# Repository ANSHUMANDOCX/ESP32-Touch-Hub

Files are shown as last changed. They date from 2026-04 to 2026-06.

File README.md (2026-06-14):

# ESP32-S3 Smart Hub

## Description
This is a ESP32-S3 Based HUB paired with a touch screen that can be used for anything that one wants but for me i will be using it to connect all my ESP32 project and control it from one place and get a whole lot more connected experience between my project.

---
## Parts Used
- ESP32 S3 Used as the brains of the system
- CH340C for onboard programming. 
- 3.5" ILI9488 SPI touch display (MSP3520 module) for UI interaction
- Battery-powered with USB-C charging and intelligent load sharing
- Onboard SD card for storing web assets, UI resources, and sensor logs
- 3 tactile buttons + passive buzzer for physical interaction and alerts
- Charging status indicators both physical and UI based
---
## Technicals 
- The board will have dual volages 5V and 3.3v for the TFT and ESP32.
- It uses a load sharing circuit where when the battery is charging the board will be powered from the USB
- I will pair a 1800mah Lipo Battery so i can get a considerable amount of battery life.
- the board is using a MT3608 and ME6217C33M5G ics for 5v and 3.3v regulator along with a MCP73833 for charging the battery

## Firmware
THe code is tested just put your wifi and password and its ready to go 

## PCB SCHEMATIC and CAD 






## BUILD 
Demo Link https://youtube.com/shorts/PqJHbwtBgcA







## BOM
| Product Name | Quantity | Price ($) | Vendor |
|---|---:|---:|---|
| [ME6217C33M5G 3.3V LDO Regulator](https://sharvielectronics.com/product/me6217c33m5g-3-3v-800ma-fixed-ldo-voltage-regulator-sot-23-5-package/) | 1 | 0.30 | Sharvi Electronics |
| [ESP32-S3-WROOM-1 N16R8](https://sharvielectronics.com/product/esp32-s3-wroom-1-n16r8-16mb-flash-memory-wifi-and-bluetooth-module-41-smd-package/) | 1 | 4.51 | Sharvi Electronics |
| [FS8205A Dual N-Channel MOSFET](https://sharvielectronics.com/product/fs8205a-dual-n-channel-power-mosfet-lithium-battery-protection-tssop-8-package/) | 1 | 0.80 | Sharvi Electronics |
| [DW01A Battery Protection IC](https://sharvielectronics.com/product/dw01a-lithium-battery-protection-ic-sot23-6/) | 1 | 0.55 | Sharvi Electronics |
| [MT3608 Step-Up Converter IC](https://sharvielectronics.com/product/mt3608-high-efficiency-1-2mhz-2a-step-up-converter-sot23-6-package/) | 1 | 0.85 | Sharvi Electronics |
| [Micro SD Card Socket 9-Pin SMD](https://sharvielectronics.com/product/micro-sd-memory-card-socket-9pin-smd/) | 1 |0.60| Sharvi Electronics |
| [MCP73833 Li-Ion Charger IC](https://robu.in/product/mcp73833-ami-un-microchip-battery-charger-for-1-cell-of-li-ion-li-pol-battery-6v-input-4-2v-1a-charge-msop-10) | 1 | 1.93 | Robu.in |
| [AO3401 P-Channel MOSFET](https://robu.in/product/ao3401a-umwyoutai-semiconductor-co-ltd-30v-4-2a-50m%cf%8910v-1-4w-400mv-1-piece-p-channel-sot-23-mosfets-rohs) | 1 | 0.37 | Robu.in |
| [3.5" TFT Touchscreen Display](https://techiesms.com/product/3-5-inch-tft-touchscreen-display/) | 1 | 11.62 | Techiesms |
| Passives (Resistors, Capacitors, Pull-ups, etc.) | Assorted | 8 | Sharvi Electronics |
|PCB||2|ALLPCB|
|SHIPPING||1||
|Total||35||

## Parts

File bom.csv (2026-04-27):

Designator | Footprint | Quantity | Value | LCSC Part #
BZ1 | Buzzer_12x9.5RM7.6 | 1 | Buzzer
C1 | 0603 | 1 | 1uF
C10, C17, C19, C9 | 0603 | 4 | 4.7uF
C11, C12, C5 | 0603 | 3 | 22uf
C13, C14, C15, C16, C18, C20 | 0603 | 6 | 100nF
C2, C3, C4 | 0603 | 3 | 0.1uF
C23, C6 | 0603 | 2 | 10uF
C7, C8 | 0603 | 2 | 0.1
D1 | D_SOD-123 | 1 | 1N4148W
D13, D3, D4, D5, D6, D8 | 0603 | 6 | LED
D2, D7 | D_SMA | 2 | SS34
J1 | JST_XH_B2B-XH-AM_1x02_P2.50mm_Vertical | 1 | Conn_01x02_Pin
J2 | USB_C_Receptacle_GCT_USB4105-xx-A_16P_TopMnt_Horizontal | 1 | USB_C_Receptacle_USB2.0_16P
L1 | IND-SMD_L4.0-W4.0 | 1 | 22uH
LCD1 | MSP3520 | 1 | MSP3520
Q1 | SOT-23 | 1 | AO3401A
Q2, Q3 | SOT-23 | 2 | SS8050
Q4 | TSSOP-8_L4.4-W3.0-P0.65-LS6.4-BL-2 | 1 | ~
Q5 | SOT-23 | 1 | MMBT2222A
R1 | 0603 | 1 | 10K Therm
R10, R11, R21 | 0603 | 3 | 100R
R12, R4, R5, R6 | 0603 | 4 | 1K
R13, R14, R15, R18, R19, R27, R28 | 0603 | 7 | 10K
R16, R17 | 0603 | 2 | 5.1K
R2 | 0603 | 1 | 2.2k
R20 | 0603 | 1 | 470R
R22, R23, R7, R9 | 0603 | 4 | 100K
R3 | 0603 | 1 | 2K
R8 | 0603 | 1 | 750k
SW1, SW4, SW5 | SW_TH_Tactile_Omron_B3F-100x | 3 | SW_Push
SW2, SW3 | SW_Push_SPST_NO_Alps_SKRK | 2 | SW_Push
TF1 | TF-SMD_TF-CARD-H1.8 | 1 | ~
U1 | ESP32-S3-WROOM-1 | 1 | ESP32-S3-WROOM-1
U2 | SOIC-16_3.9x9.9mm_P1.27mm | 1 | CH340C
U3 | MSOP-10_3x3mm_P0.5mm | 1 | MCP73833-xxx-UN
U4 | SOT-23-5 | 1 | ME6217C33M5G
U5 | SOT-23-6 | 1 | DW01A
U6 | SOT-23-6 | 1 | MT3608

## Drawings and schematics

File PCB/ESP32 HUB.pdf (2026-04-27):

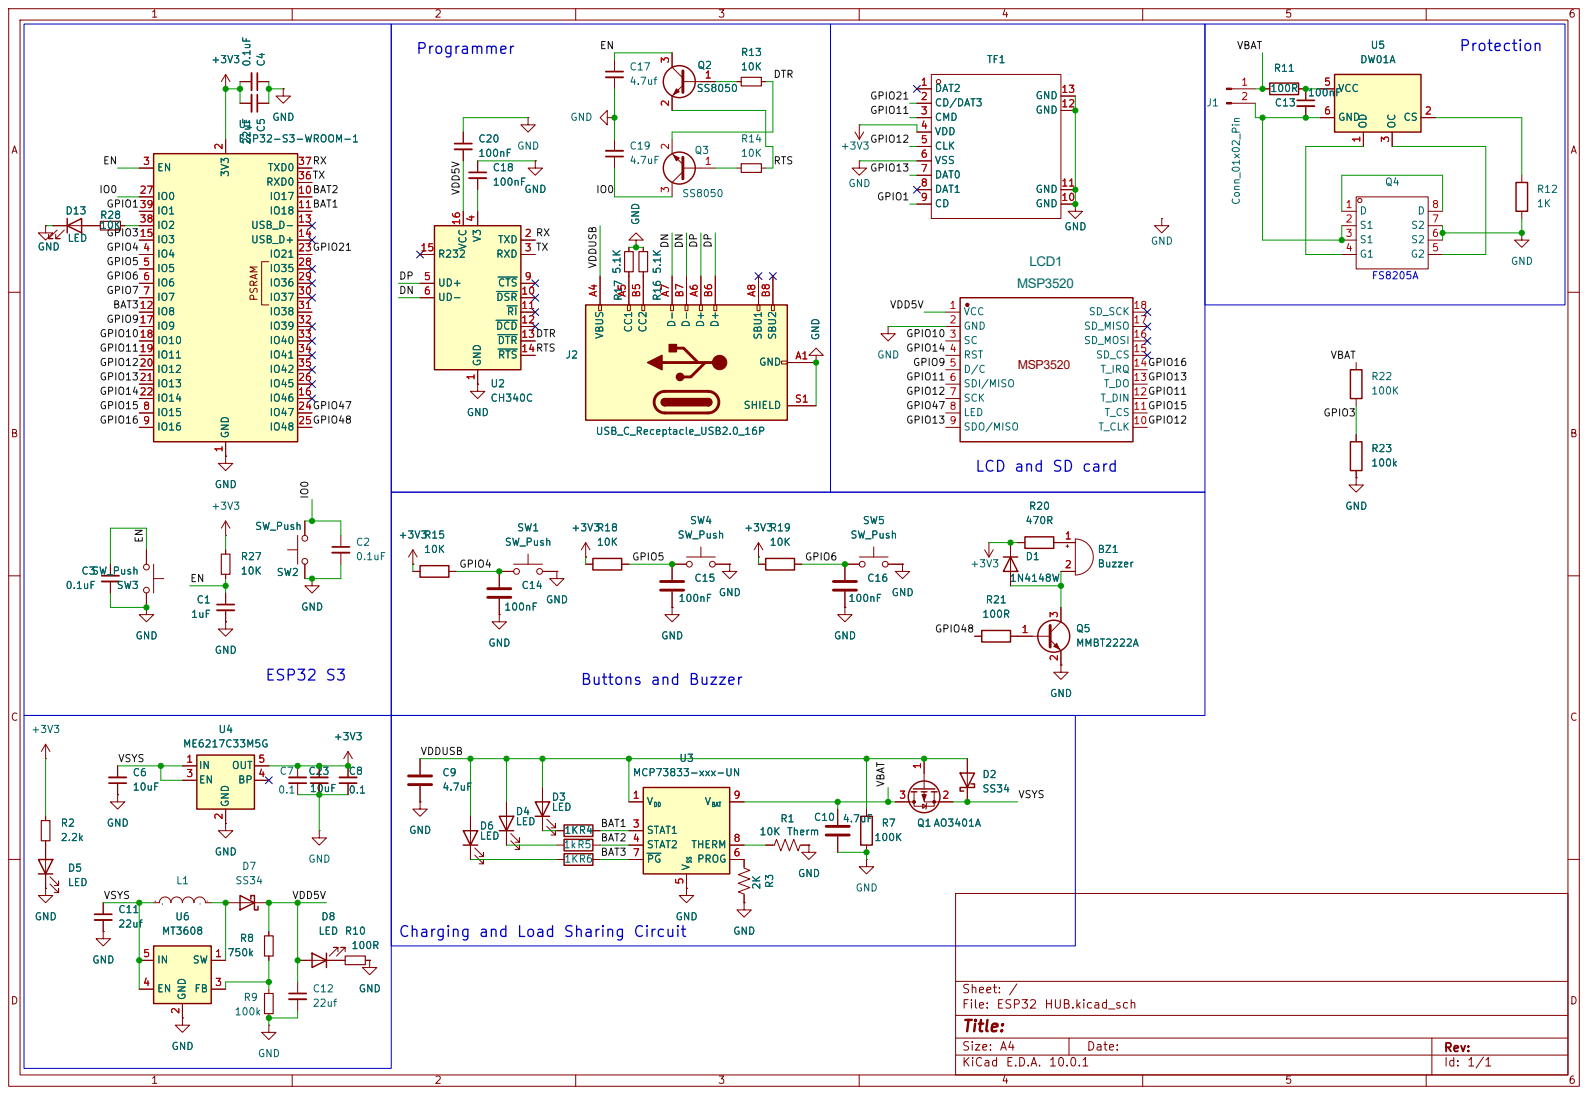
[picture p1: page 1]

4 UD+ 5 UD- 6 CTS 9 DSR 10 RI 11 DCD 12 DTR 13 RTS 14 R232 15 VCC 16 C18
GPIO1 Charging and Load Sharing Circuit

4 UD+ 5 UD- 6 CTS 9 DSR 10 RI 11 DCD 12 DTR 13 RTS 14 R232 15 VCC 16 U2CH340C PSRAM GND

LCD and SD card

Size: A4 | Rev:
KiCad E.D.A. 10.0.1 | Id: 1/1

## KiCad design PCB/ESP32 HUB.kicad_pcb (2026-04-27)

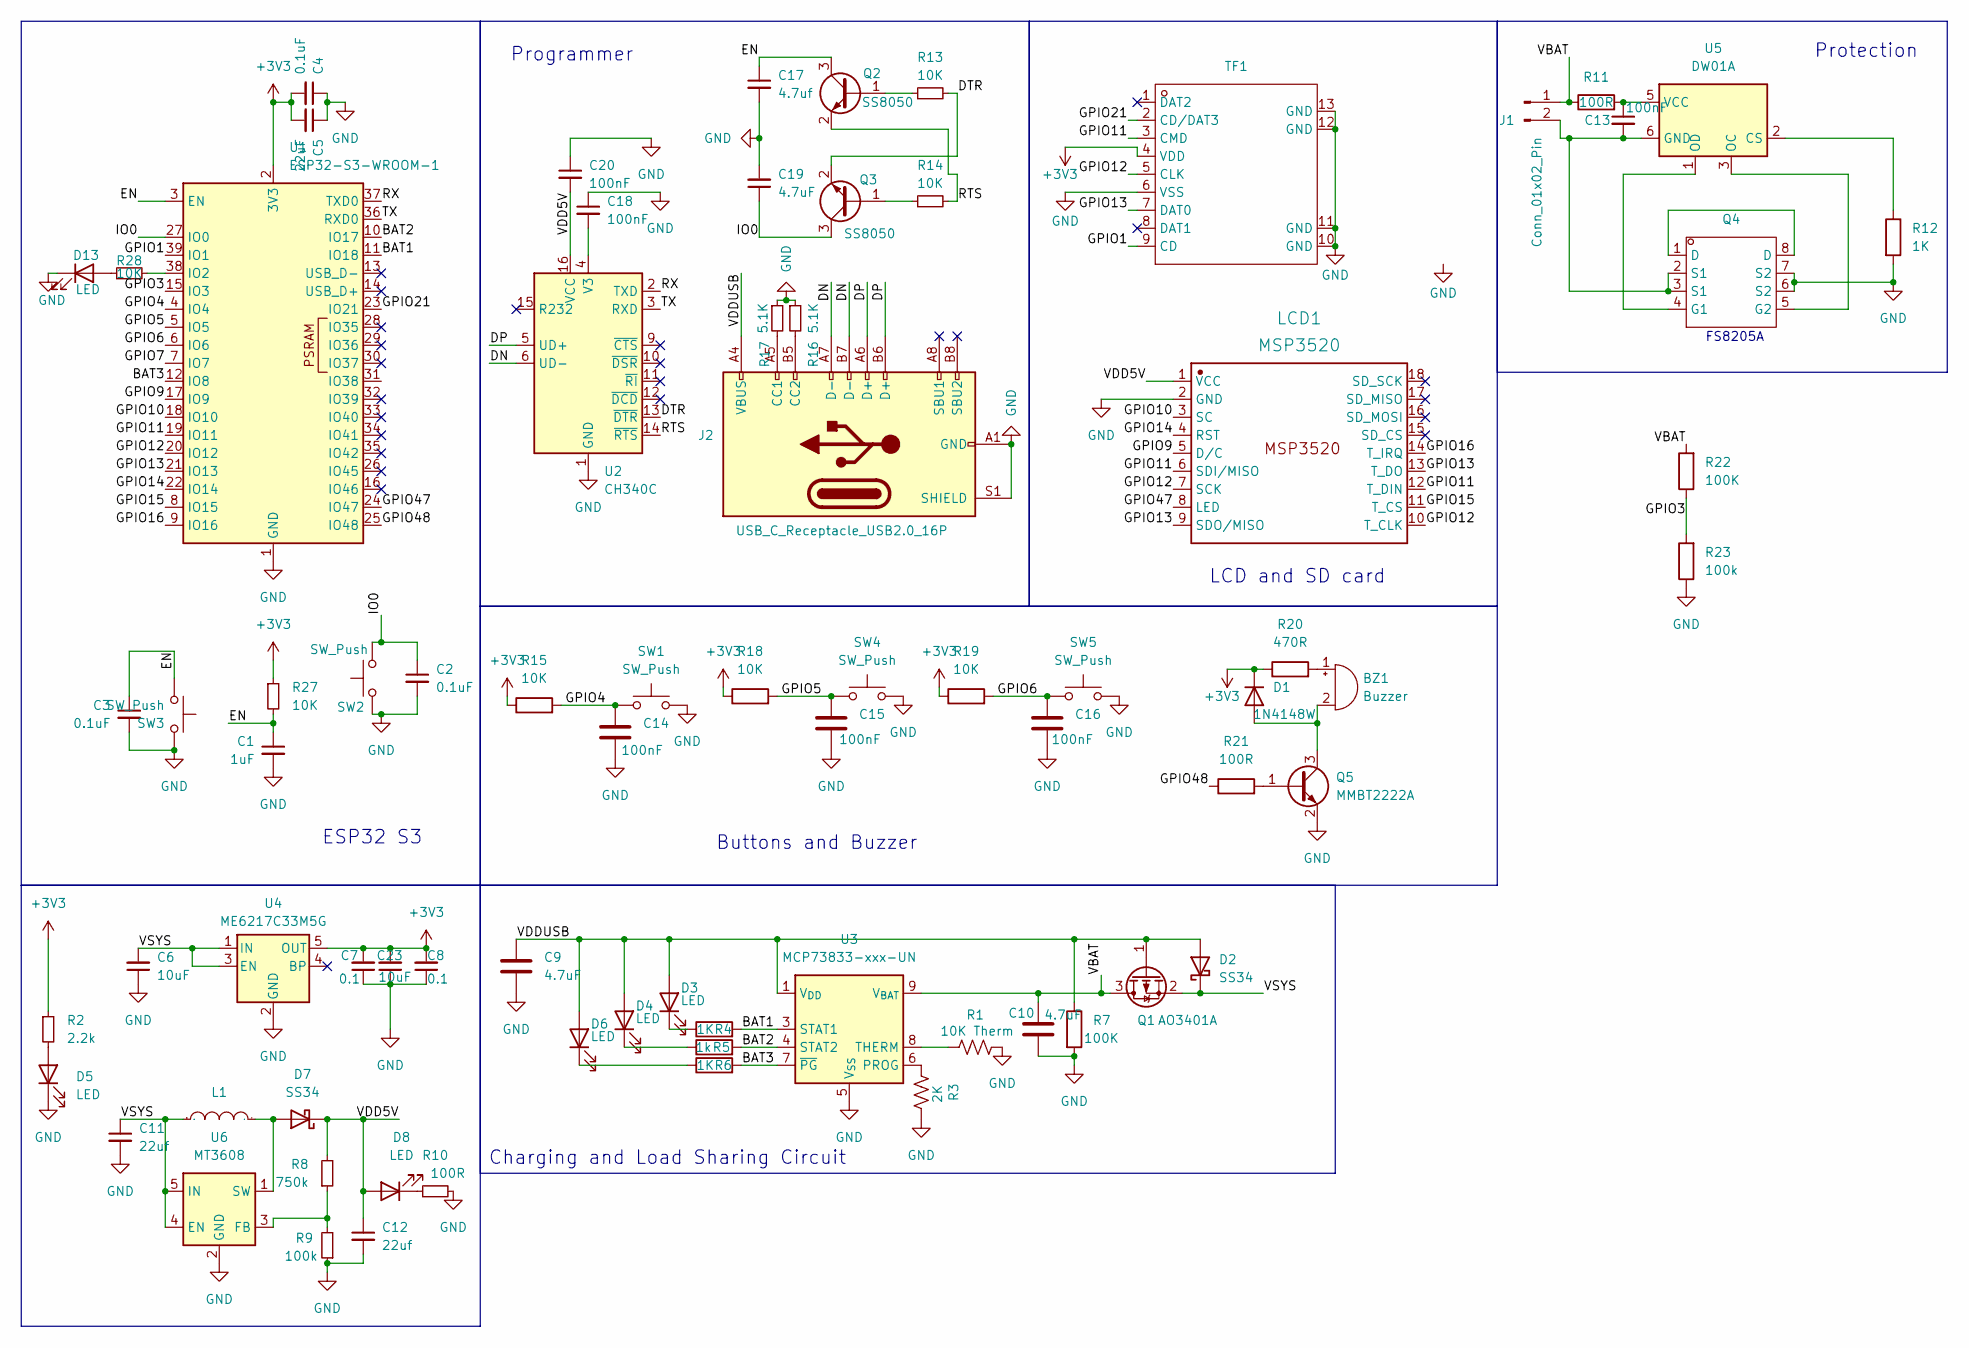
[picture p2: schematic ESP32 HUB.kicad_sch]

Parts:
BZ1: Buzzer; Buzzer_12x9.5RM7.6
C1: 1uF; C_0603_1608Metric
C2, C3, C4: 0.1uF; C_0603_1608Metric
C5: 22uF; C_0603_1608Metric
C6, C23: 10uF; C_0603_1608Metric_Pad1.08x0.95mm_HandSolder
C7, C8: 0.1; C_0603_1608Metric_Pad1.08x0.95mm_HandSolder
C9, C10: 4.7uF; C_0603_1608Metric
C11, C12: 22uf; C_0603_1608Metric
C13, C14, C15, C16: 100nF; C_0603_1608Metric
C17: 4.7uf; C_0603_1608Metric_Pad1.08x0.95mm_HandSolder
C18, C20: 100nF; C_0603_1608Metric_Pad1.08x0.95mm_HandSolder
C19: 4.7uF; C_0603_1608Metric_Pad1.08x0.95mm_HandSolder
D1: 1N4148W; D_SOD-123
D2, D7: SS34; D_SMA
D3, D4, D5, D6, D8, D13: LED; LED_0603_1608Metric
J1: Conn_01x02_Pin; JST_XH_B2B-XH-AM_1x02_P2.50mm_Vertical
J2: USB_C_Receptacle_USB2.0_16P; USB_C_Receptacle_GCT_USB4105-xx-A_16P_TopMnt_Horizontal
L1: 22uH; IND-SMD_L4.0-W4.0; Manufacturer Part ANR4030T220M; LCSC Part Name 22uH ±20% 1.4A 4x4x3mm
LCD1: MSP3520; Manufacturer Part MSP3520
Q1: AO3401A; SOT-23
Q2, Q3: SS8050; SOT-23
Q4: TSSOP-8_L4.4-W3.0-P0.65-LS6.4-BL-2; Manufacturer Part FS8205A; LCSC Part Name 2个N沟道 耐压:20V 电流:6A
Q5: MMBT2222A; SOT-23
R1: 10K Therm; R_0603_1608Metric_Pad0.98x0.95mm_HandSolder
R2: 2.2k; R_0603_1608Metric_Pad0.98x0.95mm_HandSolder
R3: 2K; R_0603_1608Metric_Pad0.98x0.95mm_HandSolder
R4, R6, R12: 1K; R_0603_1608Metric_Pad0.98x0.95mm_HandSolder
R5: 1k; R_0603_1608Metric_Pad0.98x0.95mm_HandSolder
R7, R22: 100K; R_0603_1608Metric_Pad0.98x0.95mm_HandSolder
R8: 750k; R_0603_1608Metric_Pad0.98x0.95mm_HandSolder
R9, R23: 100k; R_0603_1608Metric_Pad0.98x0.95mm_HandSolder
R10, R11, R21: 100R; R_0603_1608Metric_Pad0.98x0.95mm_HandSolder
R13, R14, R15, R18, R19, R27, R28: 10K; R_0603_1608Metric_Pad0.98x0.95mm_HandSolder
R16, R17: 5.1K; R_0603_1608Metric_Pad0.98x0.95mm_HandSolder
R20: 470R; R_0603_1608Metric_Pad0.98x0.95mm_HandSolder
SW1, SW4, SW5: SW_Push; SW_TH_Tactile_Omron_B3F-100x
SW2, SW3: SW_Push; SW_Push_SPST_NO_Alps_SKRK
TF1: TF-SMD_TF-CARD-H1.8; Manufacturer Part TF-CARD H1.8; LCSC Part Name 9P，自弹式TF卡座
U1: ESP32-S3-WROOM-1
U2: CH340C; SOIC-16_3.9x9.9mm_P1.27mm
U3: MCP73833-xxx-UN; MSOP-10_3x3mm_P0.5mm
U4: ME6217C33M5G; SOT-23-5
U5: DW01A; SOT-23-6
U6: MT3608; SOT-23-6

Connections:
+3V3: C4.2, C5.2, C7.2, C8.2, C23.2, D1.1 (K), R2.1, R15.1, R18.1, R19.1, R20.1, R27.1, TF1.4 (VDD), U1.2 (3V3), U4.5 (OUT)
/BAT1: R4.2, U1.11 (IO18), U3.3 (STAT1)
/BAT2: R5.2, U1.10 (IO17), U3.4 (STAT2)
/BAT3: R6.2, U1.12 (IO8), U3.7 (~PG)
/DN: J2.A7 (D-), J2.B7 (D-), U2.6 (UD-)
/DP: J2.A6 (D+), J2.B6 (D+), U2.5 (UD+)
/DTR: Q3.2 (E), R13.2, U2.13 (~DTR)
/EN: C1.1, C3.1, C17.1, Q2.3 (C), R27.2, SW3.1, U1.3 (EN)
/GPIO1: TF1.9 (CD), U1.39 (IO1)
/GPIO3: R22.1, R23.2, U1.15 (IO3)
/GPIO4: C14.1, R15.2, SW1.1, U1.4 (IO4)
/GPIO5: C15.1, R18.2, SW4.1, U1.5 (IO5)
/GPIO6: C16.1, R19.2, SW5.1, U1.6 (IO6)
/GPIO7: U1.7 (IO7)
/GPIO9: LCD1.5 (D/C), U1.17 (IO9)
/GPIO10: LCD1.3 (SC), U1.18 (IO10)
/GPIO11: LCD1.6 (SDI/MISO), LCD1.12 (T_DIN), TF1.3 (CMD), U1.19 (IO11)
/GPIO12: LCD1.7 (SCK), LCD1.10 (T_CLK), TF1.5 (CLK), U1.20 (IO12)
/GPIO13: LCD1.9 (SDO/MISO), LCD1.13 (T_DO), TF1.7 (DAT0), U1.21 (IO13)
/GPIO14: LCD1.4 (RST), U1.22 (IO14)
/GPIO15: LCD1.11 (T_CS), U1.8 (IO15)
/GPIO16: LCD1.14 (T_IRQ), U1.9 (IO16)
/GPIO21: TF1.2 (CD/DAT3), U1.23 (IO21)
/GPIO47: LCD1.8 (LED), U1.24 (IO47)
/GPIO48: R21.1, U1.25 (IO48)
/IO0: C2.1, C19.1, Q3.3 (C), SW2.1, U1.27 (IO0)
/RTS: Q2.2 (E), R14.2, U2.14 (~RTS)
/RX: U1.37 (TXD0), U2.2 (TXD)
/TX: U1.36 (RXD0), U2.3 (RXD)
/VBAT: C10.1, J1.1, Q1.3 (D), R11.1, R22.2, U3.9 (V_{BAT}), U3.10 (V_{BAT})
/VDD5V: C12.1, C20.2, D7.1 (K), D8.2 (A), LCD1.1 (VCC), R8.2, U2.16 (VCC)
/VDDUSB: C9.1, D2.2 (A), D3.2 (A), D4.2 (A), D6.2 (A), J2.A4 (VBUS), J2.A9 (VBUS), J2.B4 (VBUS), J2.B9 (VBUS), Q1.1 (G), R7.1, U3.1 (V_{DD}), U3.2 (V_{DD})
/VSYS: C6.2, C11.1, D2.1 (K), L1.1, Q1.2 (S), U4.1 (IN), U4.3 (EN), U6.4 (EN), U6.5 (IN)
GND: C1.2, C2.2, C3.2, C4.1, C5.1, C6.1, C7.1, C8.1, C9.2, C10.2, C11.2, C12.2, C14.2, C15.2, C16.2, C17.2, C18.1, C19.2, C20.1, C23.1, D5.1 (K), D13.1 (K), J2.A1 (GND), J2.A12 (GND), J2.B1 (GND), J2.B12 (GND), J2.S1 (SHIELD), LCD1.2 (GND), Q4.6 (S2), Q4.7 (S2), Q5.2 (E), R1.2, R3.2, R7.2, R9.1, R10.2, R12.2, R16.1, R17.1, R23.1, SW1.2, SW2.2, SW3.2, SW4.2, SW5.2, TF1.6 (VSS), TF1.10 (GND), TF1.11 (GND), TF1.12 (GND), TF1.13 (GND), U1.1 (GND), U1.40 (GND), U1.41 (GND), U2.1 (GND), U3.5 (V_{SS}), U4.2 (GND), U6.2 (GND)
unnamed: BZ1.1 (+), R20.2
unnamed: BZ1.2 (-), D1.2 (A), Q5.3 (C)
unnamed: D3.1 (K), R4.1
unnamed: D4.1 (K), R5.1
unnamed: D5.2 (A), R2.2
unnamed: D6.1 (K), R6.1
unnamed: D7.2 (A), L1.2, U6.1 (SW)
unnamed: D8.1 (K), R10.1
unnamed: D13.2 (A), R28.1
unnamed: C13.2, J1.2, Q4.2 (S1), Q4.3 (S1), U5.6 (GND)
unnamed: J2.A5 (CC1), R17.2
unnamed: J2.B5 (CC2), R16.2
unnamed: Q2.1 (B), R13.1
unnamed: Q3.1 (B), R14.1
unnamed: Q4.1 (D), Q4.8 (D)
unnamed: Q4.4 (G1), U5.1 (OD)
unnamed: Q4.5 (G2), U5.3 (OC)
unnamed: Q5.1 (B), R21.2
unnamed: R28.2, U1.38 (IO2)
unnamed: C18.2, U2.4 (V3)
unnamed: R3.1, U3.6 (PROG)
unnamed: R1.1, U3.8 (THERM)
unnamed: R12.1, U5.2 (CS)
unnamed: C13.1, R11.2, U5.5 (VCC)
unnamed: R8.1, R9.2, U6.3 (FB)

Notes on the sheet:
FS8205A
Buttons and Buzzer
Programmer
Charging and Load Sharing Circuit
LCD and SD card
Protection
ESP32 S3

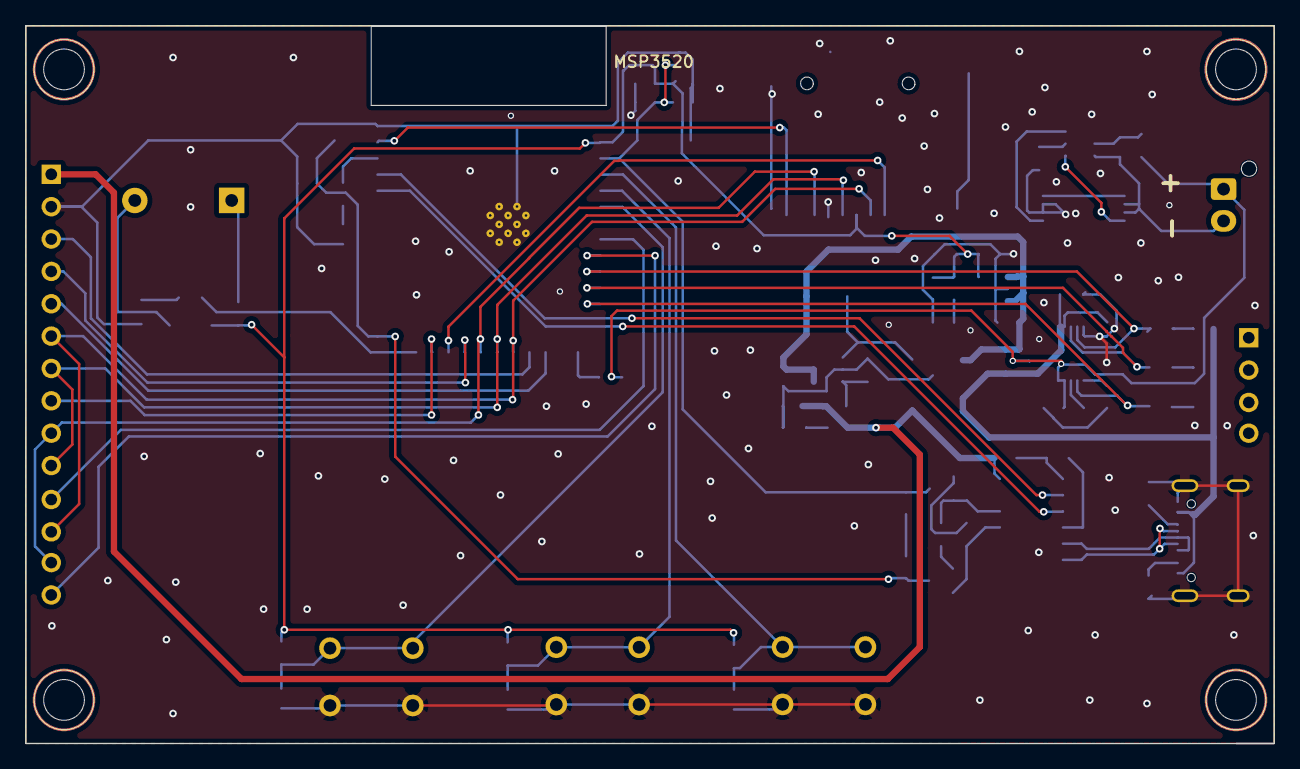
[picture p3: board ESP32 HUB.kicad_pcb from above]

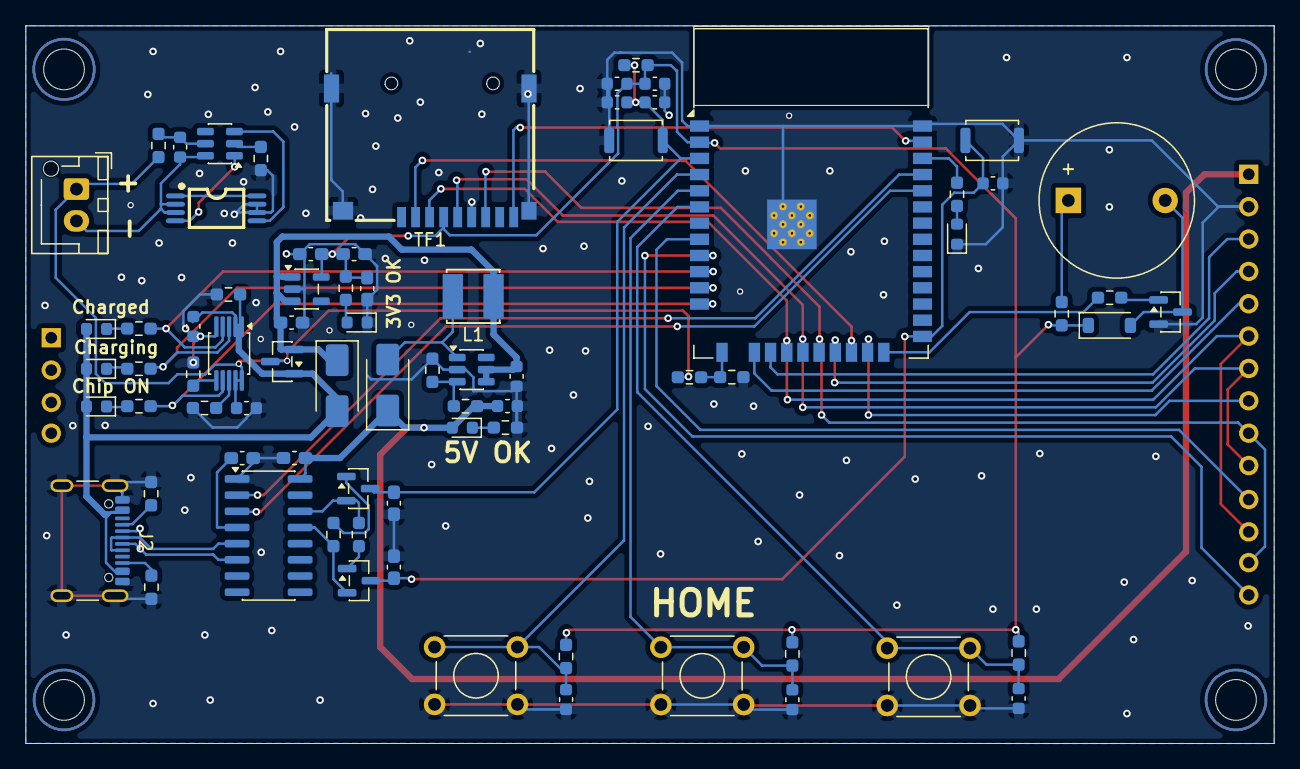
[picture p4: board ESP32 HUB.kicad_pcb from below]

Board: 2 copper layers, 98.0 x 56.3 mm, 77 parts (76 on the bottom side), 58 nets.

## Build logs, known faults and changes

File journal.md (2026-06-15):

# ESP32 Touch HUB

Its a ESP32 Hub that uses a 3.5 inch touch screen to control things

# 2026-06-14: Finally Built it 

**Total time spent: 0.2 hours**

Setup all the other dash boards and finally completed the build didnt wait for the #D printer to arrive just added some random wooden pices at the back to amke the buttons accessible 




demo video- https://youtube.com/shorts/PqJHbwtBgcA

# 2026-06-13: Setup the final Dashboard 

**Total time spent: 0.75 hours**

here is the final dashboard coded it no problems were left apart from a few the only thing now remaining is added spacers for the buttons so i can actually use those but i am waiting on getting my 3dp to get it printed also since my sensor node it not yet ready hence the sensor data is not being updated WhatsApp Image 2026-06-13 at 9.23.56 PM.jpeg

hackatime project name - ESP32 Touch HUB

# 2026-06-10: Working on the CODE

**Total time spent: 2.5 hours**

Started out by wrting a simple code to scan the wifi around me aand used the buttons to navigate the details all was fine until i tried to upload the code which was a mistake since i rushed into it and faced a lot of problem spent a lot of time debugging it and found out that my even tho my esp32s3 is n16r8 the psram is not working. after that went back to square one where i uploaded code one by one to test each section and move on 

here is the hackatime project name ESP32 Touch HUB





# 2026-06-03: Diagnosed the LCD

**Total time spent: 2 hours**

So it turns out that the touch on my LCD is faulty and i wont be able to use the touch feature any more at least not unti i get a replacement which could be a while so for now the board will be based on using the buttons i alr added good thing that i did so anyways its a dashboard so i dont think it will be a big prob just makes me sad that i wont be able to make what i intended to

the display is working fine tho just the touch 



this is what i am getting when i try to read the touch data 


# 2026-05-31: Completed PCB assembly 

**Total time spent: 5 hours**

So completed the PCB assembly today took a lot of time to completed and also faced some problems along the way 

1. Setting up the PCB for applying the paste 
this was pretty straight forward just laid the pcb i wanted past between 4 other pcbs to make it stay in one place stuck the other pcbs to my table using masking tape 


2. completed applying the paste 
the usualy 45 and 90 degree swiping the card thing pretty simple tbh nothing major but made a mistake here accidently used a old paste which was not enough wet and turned out to be a pain in the ass later on

3. Placing the component
palced all the componets by looking at the ibom from kicad 

3. reflowing the paste 
here is where i faced the problem due the quality of the paste it didnt properly reflowed so even if the solder flowed it didnt make a good joint so it was majorly a blunder 

4. Fixing the Joints
to fix em i had to manually heat every pad with a soldering iron and make sure that the joint was solid 
here is a footage i took from my microscope

https://drive.google.com/file/d/1vjfSiBI4xpelcF_Ak4XN7pS9MMJF1--t/view?usp=sharing
https://drive.google.com/file/d/1b6f4MoLTS4rwQKdUu72TKH13SkypEIQ1/view?usp=sharing

5. Inital testing 
so powered up the the board and found out that nothig blew up yay!! but it turned out the esp32 chip wasnt communicating i couldnt understand why then i took a look at my schematic and it turned out that i can connected the RX and the TX of the wrong but luckily it wasnt a very big thing just a pain in the ass to fix since i wanted it to be clean so i cut the trace and connected it using some very thin wire 
here is the footage to that its limited cuz my memory card ran out of space 
https://drive.google.com/file/d/1RYIBsxv1aN_MEL4bykIt0hbc3sjk9e4Q/view?usp=sharing
https://drive.google.com/file/d/1l4DWNKCJhttoH9iQIVY37mo3bGiGoVLq/view?usp=sharing
https://drive.google.com/file/d/1rmzW9IPVHRcFvySrBTWPCZd45q94Sqj3/view?usp=sharing
https://drive.google.com/file/d/1F8eLT4zi97B3lu4MnuW7eXseRLjP_RLU/view?usp=sharing




6. Attaching the LCD and changed the colour of the lights for better indication
Finally after everything was fixed and fine i soldered on the lcd and changed the color of the light for better indication of hte charging status





Now all thats left is the software part of the model 

# 2026-05-24: Enclosure fitments 

**Total time spent: 1 hour**

Worked on fitting the LCD flush into the enclosure it included sanding adding the heatset inserts finishing and finally adding the screws. It just feels so goos to see your measuremts for a 3d model turn out to be great when you dont event have the parts and just make it using a random datasheet and 3d model online 



that white residue is due to the acetone i used to cool the inserts turnout to be a bad idea

# 2026-04-27: More cad work

**Total time spent: 2.5 hours**

Made the Back plate of the Case along with adding the holes slots etc for the card type c port and LEDs made a mistake while designing accidently joined all the bodies together lol


# 2026-04-26: CAD work

**Total time spent: 3 hours**

did a majority of the CAD for the HUB making the main enclosure and properly aligned the holes for the dispaly


# 2026-04-26: Some changes

**Total time spent: 0.5 hours**

Ran the DRC made some changes got the 3d view had to fix a few part nothing much
Screenshot 2026-04-26 224944.png

# 2026-04-25: PCB Design Part 2

**Total time spent: 1.5 hours**

Added some markers on The Silk screen along with chaning the footprint of the SD card holder i chose the most common one out there 


# 2026-04-24: Preliminary Routing

**Total time spent: 2.5 hours**

i have completed the preliminary routing of the PCB is done all the part are routed for the first time which i thut were the best path however i will need to  take more look on it make it perfect

# 2026-04-24: PCB Design

**Total time spent: 2 hours**

Assigned footprints to the symbols along with arranging the components on the PCB at the places i want them to be


# 2026-04-23: More work on Schematic

**Total time spent: 1.5 hour**

Completed wiring of the Display SD card and the 3 keys that i will be using for navigation on the display. Even tho the display can have its own sd card but still i will be adding a microsd card slot on the main board so that it looks clean i can use a micro Sd card instead


# 2026-04-23: did the power part of the schematic

**Total time spent: 2 hours**

Soo i completed the power part of the circuit the board will have both 3.3v and 5v on board and wanted to add a extra thing which is the system will charge it elf and power the system simultaneously when i plug it in its called load sharing and it was my first time doing so so took me a lot of time figuring it out https://ww1.microchip.com/downloads/aemDocuments/documents/OTH/ProductDocuments/UserGuides/51746a.pdf


# 2026-04-22: Made the Symbol and Foot print for the MSP3520 disply

**Total time spent: 2 hours**

I took refernce from the data sheet https://www.lcdwiki.com/res/MSP3520/MSP3520_Size.pdf and made symbol and footprint for the display to be used 


# 2026-04-22: Did research for parts Along with started out with the schematic 

**Total time spent: 3 hours**

I started out by charting the features I would like to have on that HUB since my aim is to getting a device with which i will use and control all my other esp32 web projects 

other thing done is completing the basic circuit for ESP32 S3 and the programming IC which here is CH340C


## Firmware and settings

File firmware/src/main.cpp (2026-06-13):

/*
 * ============================================================
 *  ESP32-S3 Smart Hub — Concept C Dashboard
 * ============================================================
 *  Display : TFT_eSPI  ILI9488  480x320
 *  Buttons : IO4=PREV  IO5=SELECT  IO6=NEXT
 *  Screens : Dashboard -> Sensors -> NTP Clock -> Battery -> WiFi Info
 *
 *  Dashboard style: pure black, 48px time, 3x3 status grid
 *  Status colours ONLY on values — everything else near-invisible grey
 * ============================================================
 *  TFT_eSPI User_Setup.h:
 *    #define ILI9488_DRIVER
 *    #define TFT_WIDTH  320
 *    #define TFT_HEIGHT 480
 *    setRotation(1) -> 480 wide x 320 tall
 * ============================================================
 */

#include <Arduino.h>
#include <TFT_eSPI.h>
#include <WiFi.h>
#include <time.h>
#include <esp_sntp.h>

/* ─────────────────────────────────────────────────────────────
   CREDENTIALS
   ───────────────────────────────────────────────────────────── */
#define WIFI_SSID   "SSID"
#define WIFI_PASS   "PASSWORD"
#define NTP_SERVER  "pool.ntp.org"
#define NTP_SERVER2 "time.google.com"
#define NTP_SERVER3 "time.cloudflare.com"
#define GMT_OFFSET  19800
#define DST_OFFSET  0

/* ─────────────────────────────────────────────────────────────
   PINS
   ───────────────────────────────────────────────────────────── */
#define BTN_PREV      4
#define BTN_SELECT    5
#define BTN_NEXT      6
#define TFT_BL       47
#define PIN_CHARGING 18
#define PIN_CHARGED  17
#define PIN_VIN       8
#define BATT_ADC_PIN  3

#define BATT_ADC_SAMPLES 16
#define BATT_V_DIVIDER   2.0f
#define BATT_ADC_VREF    3.3f
#define BATT_ADC_MAX     4095.0f
#define BATT_V_MAX       4.20f
#define BATT_V_MIN       3.00f

/* ─────────────────────────────────────────────────────────────
   DISPLAY CONSTANTS
   ───────────────────────────────────────────────────────────── */
#define SCR_W  480
#define SCR_H  320
#define HDR_H   26
#define FTR_H   20
#define BODY_Y  HDR_H
#define BODY_H  (SCR_H - HDR_H - FTR_H)

/*
 * Concept C palette (RGB565)
 *
 * Pure black bg, near-invisible borders, white/dim text.
 * Colour ONLY on status values: green=good, amber=warn, red=bad.
 *
 * RGB888 -> RGB565 conversion: R>>3 <<11 | G>>2 <<5 | B>>3
 *
 * #0c0c0f -> 00001 000001 00001 -> 0x0841  (very close, use as BG)
 * #181820 -> 00011 000011 00100 -> 0x18C4  (grid lines / separator)
 * #2e2e38 -> 00101 010111 00111 -> 0x2B87  (dim labels)
 * #d0d0d0 -> 11010 011010 11010 -> 0xD39A  (primary text)
 * #e8e8e8 -> 11101 011101 11101 -> 0xEF7D  (bright time digits)
 * #4ade80 -> 01001 101011 10000 -> 0x4D50  (green - connected/good)
 * #fbbf24 -> 11111 010111 00100 -> 0xFAE4  (amber - warning)
 * #f87171 -> 11111 000111 01110 -> 0xF38E  (red - error)
 */
#define C_BG     0x0841   /* #0c0c0f  background          */
#define C_GRID   0x18C4   /* #181820  1px grid lines       */
#define C_DIM    0x2B87   /* #2e2e38  labels, sub-text     */
#define C_TEXT   0xD39A   /* #d0d0d0  normal values        */
#define C_BRIGHT 0xEF7D   /* #e8e8e8  big clock digits     */
#define C_GREEN  0x4D50   /* #4ade80  good / connected     */
#define C_AMBER  0xFAE4   /* #fbbf24  warning / charging   */
#define C_RED    0xF38E   /* #f87171  error / low batt     */

/* ─────────────────────────────────────────────────────────────
   SCREENS
   ───────────────────────────────────────────────────────────── */
enum Screen {
    SCR_DASHBOARD = 0,
    SCR_SENSORS,
    SCR_NTP_CLOCK,
    SCR_BATTERY,
    SCR_WIFI_INFO,
    SCR_COUNT
};

const char* SCREEN_TITLES[SCR_COUNT] = {
    "DASHBOARD", "SENSORS", "NTP CLOCK", "BATTERY", "WIFI INFO"
};

/* ─────────────────────────────────────────────────────────────
   STATE
   ───────────────────────────────────────────────────────────── */
struct BattState {
    float voltage    = 0.0f;
    int   pct        = 0;
    int   adcRaw     = 0;
    bool  charging   = false;
    bool  charged    = false;
    bool  powered    = false;
    float sessionMin = 9.9f;
    float sessionMax = 0.0f;
    float sessionSum = 0.0f;
    int   sessionN   = 0;
};

struct NTPState {
    bool   synced        = false;
    int    syncCount     = 0;
    time_t lastSyncEpoch = 0;
};

struct SensorData {
    bool  tempValid = false;  float tempC   = 0.0f;
    bool  humValid  = false;  float humPct  = 0.0f;
    bool  presValid = false;  float presHpa = 0.0f;
};

BattState  batt;
NTPState   ntpst;
SensorData sensors;

TFT_eSPI tft = TFT_eSPI();

Screen currentScreen  = SCR_DASHBOARD;
bool   needFullRedraw = true;

unsigned long lastBtnTime     = 0;
unsigned long bootMillis      = 0;
unsigned long lastBattRead    = 0;
unsigned long lastNTPSync     = 0;
unsigned long lastLiveRefresh = 0;

#define DEBOUNCE_MS        180
#define BATT_READ_INTERVAL 5000
#define NTP_SYNC_INTERVAL  600000UL
#define LIVE_REFRESH_MS    1000

/* ─────────────────────────────────────────────────────────────
   UTILITIES
   ───────────────────────────────────────────────────────────── */
bool btnPressed(int pin) {
    if (digitalRead(pin) == LOW && millis() - lastBtnTime > DEBOUNCE_MS) {
        lastBtnTime = millis();
        return true;
    }
    return false;
}

String uptimeStr() {
    unsigned long s = (millis() - bootMillis) / 1000;
    unsigned long h = s / 3600; s %= 3600;
    unsigned long m = s / 60;   s %= 60;
    char buf[12];
    snprintf(buf, sizeof(buf), "%02lu:%02lu:%02lu", h, m, s);
    return String(buf);
}

String timeStr() {
    time_t now = time(nullptr);
    struct tm t;
    localtime_r(&now, &t);
    char buf[10];
    snprintf(buf, sizeof(buf), "%02d:%02d:%02d", t.tm_hour, t.tm_min, t.tm_sec);
    return String(buf);
}

String dateStr() {
    time_t now = time(nullptr);
    struct tm t;
    localtime_r(&now, &t);
    const char* days[]   = {"SUN","MON","TUE","WED","THU","FRI","SAT"};
    const char* months[] = {"JAN","FEB","MAR","APR","MAY","JUN",
                             "JUL","AUG","SEP","OCT","NOV","DEC"};
    char buf[32];
    snprintf(buf, sizeof(buf), "%s · %02d %s %04d",
             days[t.tm_wday], t.tm_mday, months[t.tm_mon], t.tm_year + 1900);
    return String(buf);
}

uint16_t rssiColor(int rssi) {
    if (rssi > -65) return C_GREEN;
    if (rssi > -75) return C_AMBER;
    return C_RED;
}

const char* rssiLabel(int rssi) {
    if (rssi > -50) return "Excellent";
    if (rssi > -65) return "Good";
    if (rssi > -75) return "Fair";
    if (rssi > -85) return "Weak";
    return "Poor";
}

int rssiBars(int rssi) {
    if (rssi > -50) return 4;
    if (rssi > -65) return 3;
    if (rssi > -75) return 2;
    if (rssi > -85) return 1;
    return 0;
}

String battStateStr() {
    if (batt.charged)  return "Charged";
    if (batt.charging) return "Charging";
    if (batt.powered)  return "Powered";
    return "On Battery";
}

uint16_t battValueColor() {
    if (batt.charged)  return C_GREEN;
    if (batt.charging) return C_AMBER;
    if (batt.powered)  return C_GREEN;
    if (batt.pct < 15) return C_RED;
    if (batt.pct < 40) return C_AMBER;
    return C_GREEN;
}

/* ─────────────────────────────────────────────────────────────
   BATTERY READ
   ───────────────────────────────────────────────────────────── */
void readBattery() {
    uint32_t sum = 0;
    for (int i = 0; i < BATT_ADC_SAMPLES; i++) {
        sum += analogRead(BATT_ADC_PIN);
        delayMicroseconds(100);
    }
    batt.adcRaw  = (int)(sum / BATT_ADC_SAMPLES);
    batt.voltage = ((float)batt.adcRaw / BATT_ADC_MAX) * BATT_ADC_VREF * BATT_V_DIVIDER;
    float v      = constrain(batt.voltage, BATT_V_MIN, BATT_V_MAX);
    batt.pct     = (int)(((v - BATT_V_MIN) / (BATT_V_MAX - BATT_V_MIN)) * 100.0f);
    batt.charging = (digitalRead(PIN_CHARGING) == LOW);
    batt.charged  = (digitalRead(PIN_CHARGED)  == LOW);
    batt.powered  = (digitalRead(PIN_VIN)      == LOW);
    if (batt.voltage < batt.sessionMin) batt.sessionMin = batt.voltage;
    if (batt.voltage > batt.sessionMax) batt.sessionMax = batt.voltage;
    batt.sessionSum += batt.voltage;
    batt.sessionN++;
}

/* ─────────────────────────────────────────────────────────────
   NTP SYNC
   ───────────────────────────────────────────────────────────── */
void doNTPSync() {
    if (WiFi.status() != WL_CONNECTED) return;

    static bool configured = false;
    if (!configured) {
        configTime(GMT_OFFSET, DST_OFFSET, NTP_SERVER, NTP_SERVER2, NTP_SERVER3);
        configured = true;
        Serial.println("[NTP] configTime called");
    } else {
        sntp_restart();
        Serial.println("[NTP] sntp_restart called");
    }

    Serial.print("[NTP] waiting");
    unsigned long t0 = millis();
    while (time(nullptr) < 1000000000UL && millis() - t0 < 10000) {
        delay(200);
        Serial.print(".");
    }
    Serial.println();

    time_t now = time(nullptr);
    Serial.printf("[NTP] epoch=%lu\n", (unsigned long)now);

    if (now > 1000000000UL) {
        ntpst.synced        = true;
        ntpst.syncCount++;
        ntpst.lastSyncEpoch = now;
        lastNTPSync         = millis();
        Serial.println("[NTP] OK");
    } else {
        Serial.println("[NTP] FAILED");
    }
}

/* ─────────────────────────────────────────────────────────────
   HEADER  (26px)
   Title left · nav dots centre · battery % right
   ───────────────────────────────────────────────────────────── */
void drawHeader(const char* title) {
    tft.fillRect(0, 0, SCR_W, HDR_H, C_BG);
    tft.drawFastHLine(0, HDR_H - 1, SCR_W, C_GRID);

    tft.setTextSize(1);
    tft.setTextColor(C_DIM);
    tft.setCursor(8, 9);
    tft.print(title);

    int dotX = (SCR_W - SCR_COUNT * 10) / 2;
    for (int i = 0; i < SCR_COUNT; i++) {
        uint16_t col = (i == (int)currentScreen) ? C_TEXT : C_GRID;
        tft.fillCircle(dotX + i * 10, HDR_H / 2, 2, col);
    }

    char bpct[8];
    snprintf(bpct, sizeof(bpct), "%d%%", batt.pct);
    int bw = strlen(bpct) * 6;
    tft.setTextColor(battValueColor());
    tft.setCursor(SCR_W - bw - 8, 9);
    tft.print(bpct);
}

/* ─────────────────────────────────────────────────────────────
   FOOTER  (20px)
   ───────────────────────────────────────────────────────────── */
void drawFooter(const char* left, const char* mid, const char* right) {
    tft.fillRect(0, SCR_H - FTR_H, SCR_W, FTR_H, C_BG);
    tft.drawFastHLine(0, SCR_H - FTR_H, SCR_W, C_GRID);
    tft.setTextSize(1);
    tft.setTextColor(C_DIM);
    tft.setCursor(8, SCR_H - FTR_H + 6);
    tft.print(left);
    int mw = strlen(mid) * 6;
    tft.setCursor((SCR_W - mw) / 2, SCR_H - FTR_H + 6);
    tft.print(mid);
    int rw = strlen(right) * 6;
    tft.setCursor(SCR_W - rw - 8, SCR_H - FTR_H + 6);
    tft.print(right);
}

/* ─────────────────────────────────────────────────────────────
   GRID CELL HELPER
   Draws a single cell with a dim label and a coloured value.
   sub is optional (pass "" to skip).
   ───────────────────────────────────────────────────────────── */
void drawCell(int x, int y, int w, int h,
              const char* label, const char* value, uint16_t valColor,
              const char* sub)
{
    tft.setTextSize(1);
    tft.setTextColor(C_DIM);
    tft.setCursor(x + 6, y + 5);
    tft.print(label);

    tft.setTextSize(2);
    tft.setTextColor(valColor);
    tft.setCursor(x + 6, y + 17);
    tft.print(value);

    if (sub && sub[0]) {
        tft.setTextSize(1);
        tft.setTextColor(C_DIM);
        tft.setCursor(x + 6, y + h - 11);
        tft.print(sub);
    }
}

/* ─────────────────────────────────────────────────────────────
   SCREEN 0 — DASHBOARD  (Concept C)
   ───────────────────────────────────────────────────────────── */

/*
 * Layout (480 x 274 body):
 *
 *  [  48px clock + 12px date = 68px  ]
 *  [  1px gap line                   ]
 *  [  3 x 3 grid  = 205px            ]
 *  Total ~274  body height ok
 *
 * Grid: 3 cols x 3 rows, 1px separators from C_GRID
 *   col widths: 160 | 160 | 160  (480 / 3)
 *   row heights: 68 | 68 | 69    (205 / 3, last row gets remainder)
 */
#define GRID_COLS 3
#define GRID_ROWS 3
#define CELL_W    160
#define CELL_H     68
#define CLOCK_H    62   /* big time + date block height */
#define GRID_Y    (BODY_Y + CLOCK_H + 2)

void drawGridLines() {
    int gridBottom = GRID_Y + CELL_H * GRID_ROWS + (GRID_ROWS - 1);
    /* horizontal separators */
    for (int r = 1; r < GRID_ROWS; r++) {
        int gy = GRID_Y + r * (CELL_H + 1) - 1;
        tft.drawFastHLine(0, gy, SCR_W, C_GRID);
    }
    /* vertical separators */
    for (int c = 1; c < GRID_COLS; c++) {
        int gx = c * (CELL_W + 1) - 1;
        tft.drawFastVLine(gx, GRID_Y, gridBottom - GRID_Y, C_GRID);
    }
}

void drawDashboard() {
    tft.fillRect(0, BODY_Y, SCR_W, BODY_H, C_BG);
    drawHeader("DASHBOARD");

    /* ── Big clock ── */
    String t = timeStr();
    /* textSize(4): each char 6*4=24px wide, 8*4=32px tall */
    tft.setTextSize(4);
    tft.setTextColor(C_BRIGHT);
    tft.setCursor(8, BODY_Y + 6);
    tft.print(t);

    /* ── Date sub-line ── */
    String d = dateStr();
    tft.setTextSize(1);
    tft.setTextColor(C_DIM);
    tft.setCursor(10, BODY_Y + 46);
    tft.print(d);

    /* ── Thin separator ── */
    tft.drawFastHLine(0, BODY_Y + CLOCK_H, SCR_W, C_GRID);

    /* ── Grid lines ── */
    drawGridLines();

    /* ── Cell data ── */
    /* Row 0 */
    /* WIFI */
    {
        int cx = 0, cy = GRID_Y;
        if (WiFi.status() == WL_CONNECTED) {
            String ssid = WiFi.SSID();
            if (ssid.length() > 10) ssid = ssid.substring(0, 9) + "~";
            char sub[20];
            snprintf(sub, sizeof(sub), "%ddBm %s", WiFi.RSSI(), rssiLabel(WiFi.RSSI()));
            drawCell(cx, cy, CELL_W, CELL_H, "WIFI",
                     ssid.c_str(), C_GREEN, sub);
        } else {
            drawCell(cx, cy, CELL_W, CELL_H, "WIFI", "No WiFi", C_RED, "");
        }
    }
    /* BATTERY */
    {
        int cx = CELL_W + 1, cy = GRID_Y;
        char vbuf[10];
        snprintf(vbuf, sizeof(vbuf), "%.2fV", batt.voltage);
        char sub[20];
        snprintf(sub, sizeof(sub), "%d%% %s", batt.pct, battStateStr().c_str());
        drawCell(cx, cy, CELL_W, CELL_H, "BATTERY", vbuf, battValueColor(), sub);
    }
    /* UPTIME */
    {
        int cx = (CELL_W + 1) * 2, cy = GRID_Y;
        drawCell(cx, cy, CELL_W, CELL_H, "UPTIME",
                 uptimeStr().c_str(), C_TEXT, "hh:mm:ss");
    }

    /* Row 1 */
    int row1Y = GRID_Y + CELL_H + 1;
    /* TEMP */
    {
        int cx = 0, cy = row1Y;
        if (sensors.tempValid) {
            char tb[10]; snprintf(tb, sizeof(tb), "%.1fC", sensors.tempC);
            drawCell(cx, cy, CELL_W, CELL_H, "TEMP", tb, C_AMBER, "");
        } else {
            drawCell(cx, cy, CELL_W, CELL_H, "TEMP", "--", C_DIM, "pending");
        }
    }
    /* HUMIDITY */
    {
        int cx = CELL_W + 1, cy = row1Y;
        if (sensors.humValid) {
            char hb[10]; snprintf(hb, sizeof(hb), "%.0f%%", sensors.humPct);
            drawCell(cx, cy, CELL_W, CELL_H, "HUMIDITY", hb, C_TEXT, "");
        } else {
            drawCell(cx, cy, CELL_W, CELL_H, "HUMIDITY", "--", C_DIM, "pending");
        }
    }
    /* PRESSURE */
    {
        int cx = (CELL_W + 1) * 2, cy = row1Y;
        if (sensors.presValid) {
            char pb[12]; snprintf(pb, sizeof(pb), "%.0fhPa", sensors.presHpa);
            drawCell(cx, cy, CELL_W, CELL_H, "PRESSURE", pb, C_TEXT, "");
        } else {
            drawCell(cx, cy, CELL_W, CELL_H, "PRESSURE", "--", C_DIM, "pending");
        }
    }

    /* Row 2 */
    int row2Y = GRID_Y + (CELL_H + 1) * 2;
    /* NTP SYNC */
    {
        int cx = 0, cy = row2Y;
        char sub[12]; snprintf(sub, sizeof(sub), "count: %d", ntpst.syncCount);
        drawCell(cx, cy, CELL_W, CELL_H, "NTP SYNC",
                 ntpst.synced ? "Synced" : "No Sync",
                 ntpst.synced ? C_GREEN : C_RED,
                 ntpst.synced ? sub : "");
    }
    /* BATT ADC */
    {
        int cx = CELL_W + 1, cy = row2Y;
        char ab[8]; snprintf(ab, sizeof(ab), "%d", batt.adcRaw);
        drawCell(cx, cy, CELL_W, CELL_H, "BATT ADC", ab, C_TEXT, "12-bit raw");
    }
    /* POWER */
    {
        int cx = (CELL_W + 1) * 2, cy = row2Y;
        drawCell(cx, cy, CELL_W, CELL_H, "POWER",
                 battStateStr().c_str(), battValueColor(), "");
    }

    drawFooter("< PREV", "SEL = REFRESH", "NEXT >");
}
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
void loop() {

    if (btnPressed(BTN_PREV)) {
        currentScreen  = (Screen)(((int)currentScreen - 1 + SCR_COUNT) % SCR_COUNT);
        needFullRedraw = true;
    }
    if (btnPressed(BTN_NEXT)) {
        currentScreen  = (Screen)(((int)currentScreen + 1) % SCR_COUNT);
        needFullRedraw = true;
    }
    if (btnPressed(BTN_SELECT)) {
        handleSelect();
    }

    /* Battery read every 5 s */
    if (millis() - lastBattRead >= BATT_READ_INTERVAL) {
        readBattery();
        lastBattRead = millis();
    }

    /* NTP re-sync every 10 min */
    if (WiFi.status() == WL_CONNECTED &&
        millis() - lastNTPSync >= NTP_SYNC_INTERVAL) {
        doNTPSync();
    }

    /* 1-second partial refresh */
    if (!needFullRedraw && millis() - lastLiveRefresh >= LIVE_REFRESH_MS) {
        lastLiveRefresh = millis();

        if (currentScreen == SCR_NTP_CLOCK) {
            updateClockPartial();
            drawHeader("NTP CLOCK");

        } else if (currentScreen == SCR_DASHBOARD) {
            /*
             * Partial update: only the big clock area.
             * Clock: textSize(4) at x=8, y=BODY_Y+6 → 32px tall → bottom BODY_Y+38
             * Date:  textSize(1) at y=BODY_Y+46     →  8px tall → bottom BODY_Y+54
             * Clear BODY_Y to BODY_Y+56, then redraw both lines.
             */
            tft.fillRect(0, BODY_Y, SCR_W, 56, C_BG);
            tft.setTextSize(4); tft.setTextColor(C_BRIGHT);
            tft.setCursor(8, BODY_Y + 6);
            tft.print(timeStr());
            tft.setTextSize(1); tft.setTextColor(C_DIM);
            tft.setCursor(10, BODY_Y + 46);
            tft.print(dateStr());
            drawHeader("DASHBOARD");

        } else {
            drawHeader(SCREEN_TITLES[(int)currentScreen]);
        }
    }

    /* Full redraw */
    if (needFullRedraw) {
        drawCurrentScreen();
        lastLiveRefresh = millis();
    }
}

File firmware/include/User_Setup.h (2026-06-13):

#ifndef USER_SETUP_H
#define USER_SETUP_H

#define USER_SETUP_INFO "ESP32S3_ILI9488"

#define ILI9488_DRIVER

// Display size
#define TFT_WIDTH  320
#define TFT_HEIGHT 480

// SPI pins
#define TFT_MOSI 12
#define TFT_SCLK 13
#define TFT_MISO -1

#define TFT_CS   14
#define TFT_DC   11
#define TFT_RST  9

// Fonts
#define LOAD_GLCD
#define LOAD_FONT2
#define LOAD_FONT4
#define LOAD_FONT6
#define LOAD_FONT7
#define LOAD_FONT8
#define LOAD_GFXFF

#define SMOOTH_FONT

// SPI speeds
#define SPI_FREQUENCY      27000000
#define SPI_READ_FREQUENCY 20000000

#endif
